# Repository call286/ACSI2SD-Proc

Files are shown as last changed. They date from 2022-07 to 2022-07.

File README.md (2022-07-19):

# ACSI2SD-Proc
version for QFP100 controller
ACSI0123_512M.xml contains default configuration for scsi2sd-util

# Hardware - finally with placement help and board layout

- Board layout isn't the original layout, it's just for helping with rough position of parts
- DRC/ERC passing
- interactive BOM in kicad folder

Board Render Front           |  Board Render Back
:-------------------------:|:-------------------------:
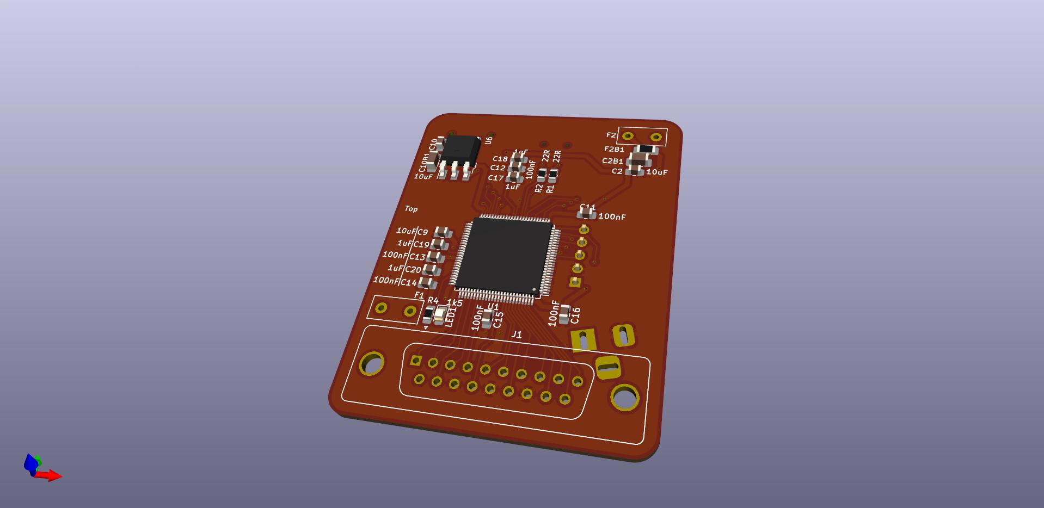
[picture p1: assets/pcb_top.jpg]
Board Render Front
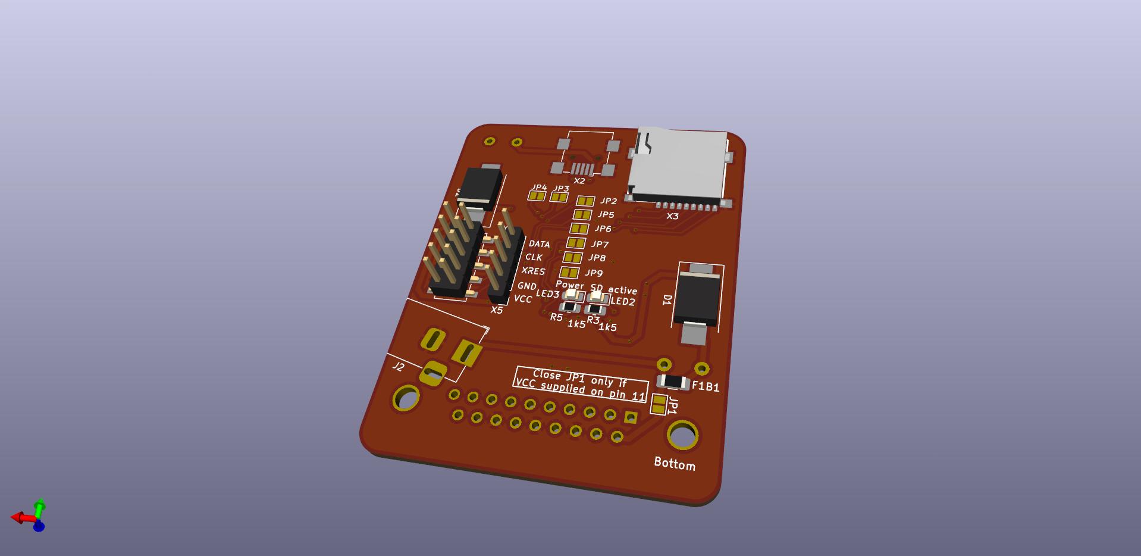
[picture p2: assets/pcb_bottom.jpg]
Board Render Back
 |

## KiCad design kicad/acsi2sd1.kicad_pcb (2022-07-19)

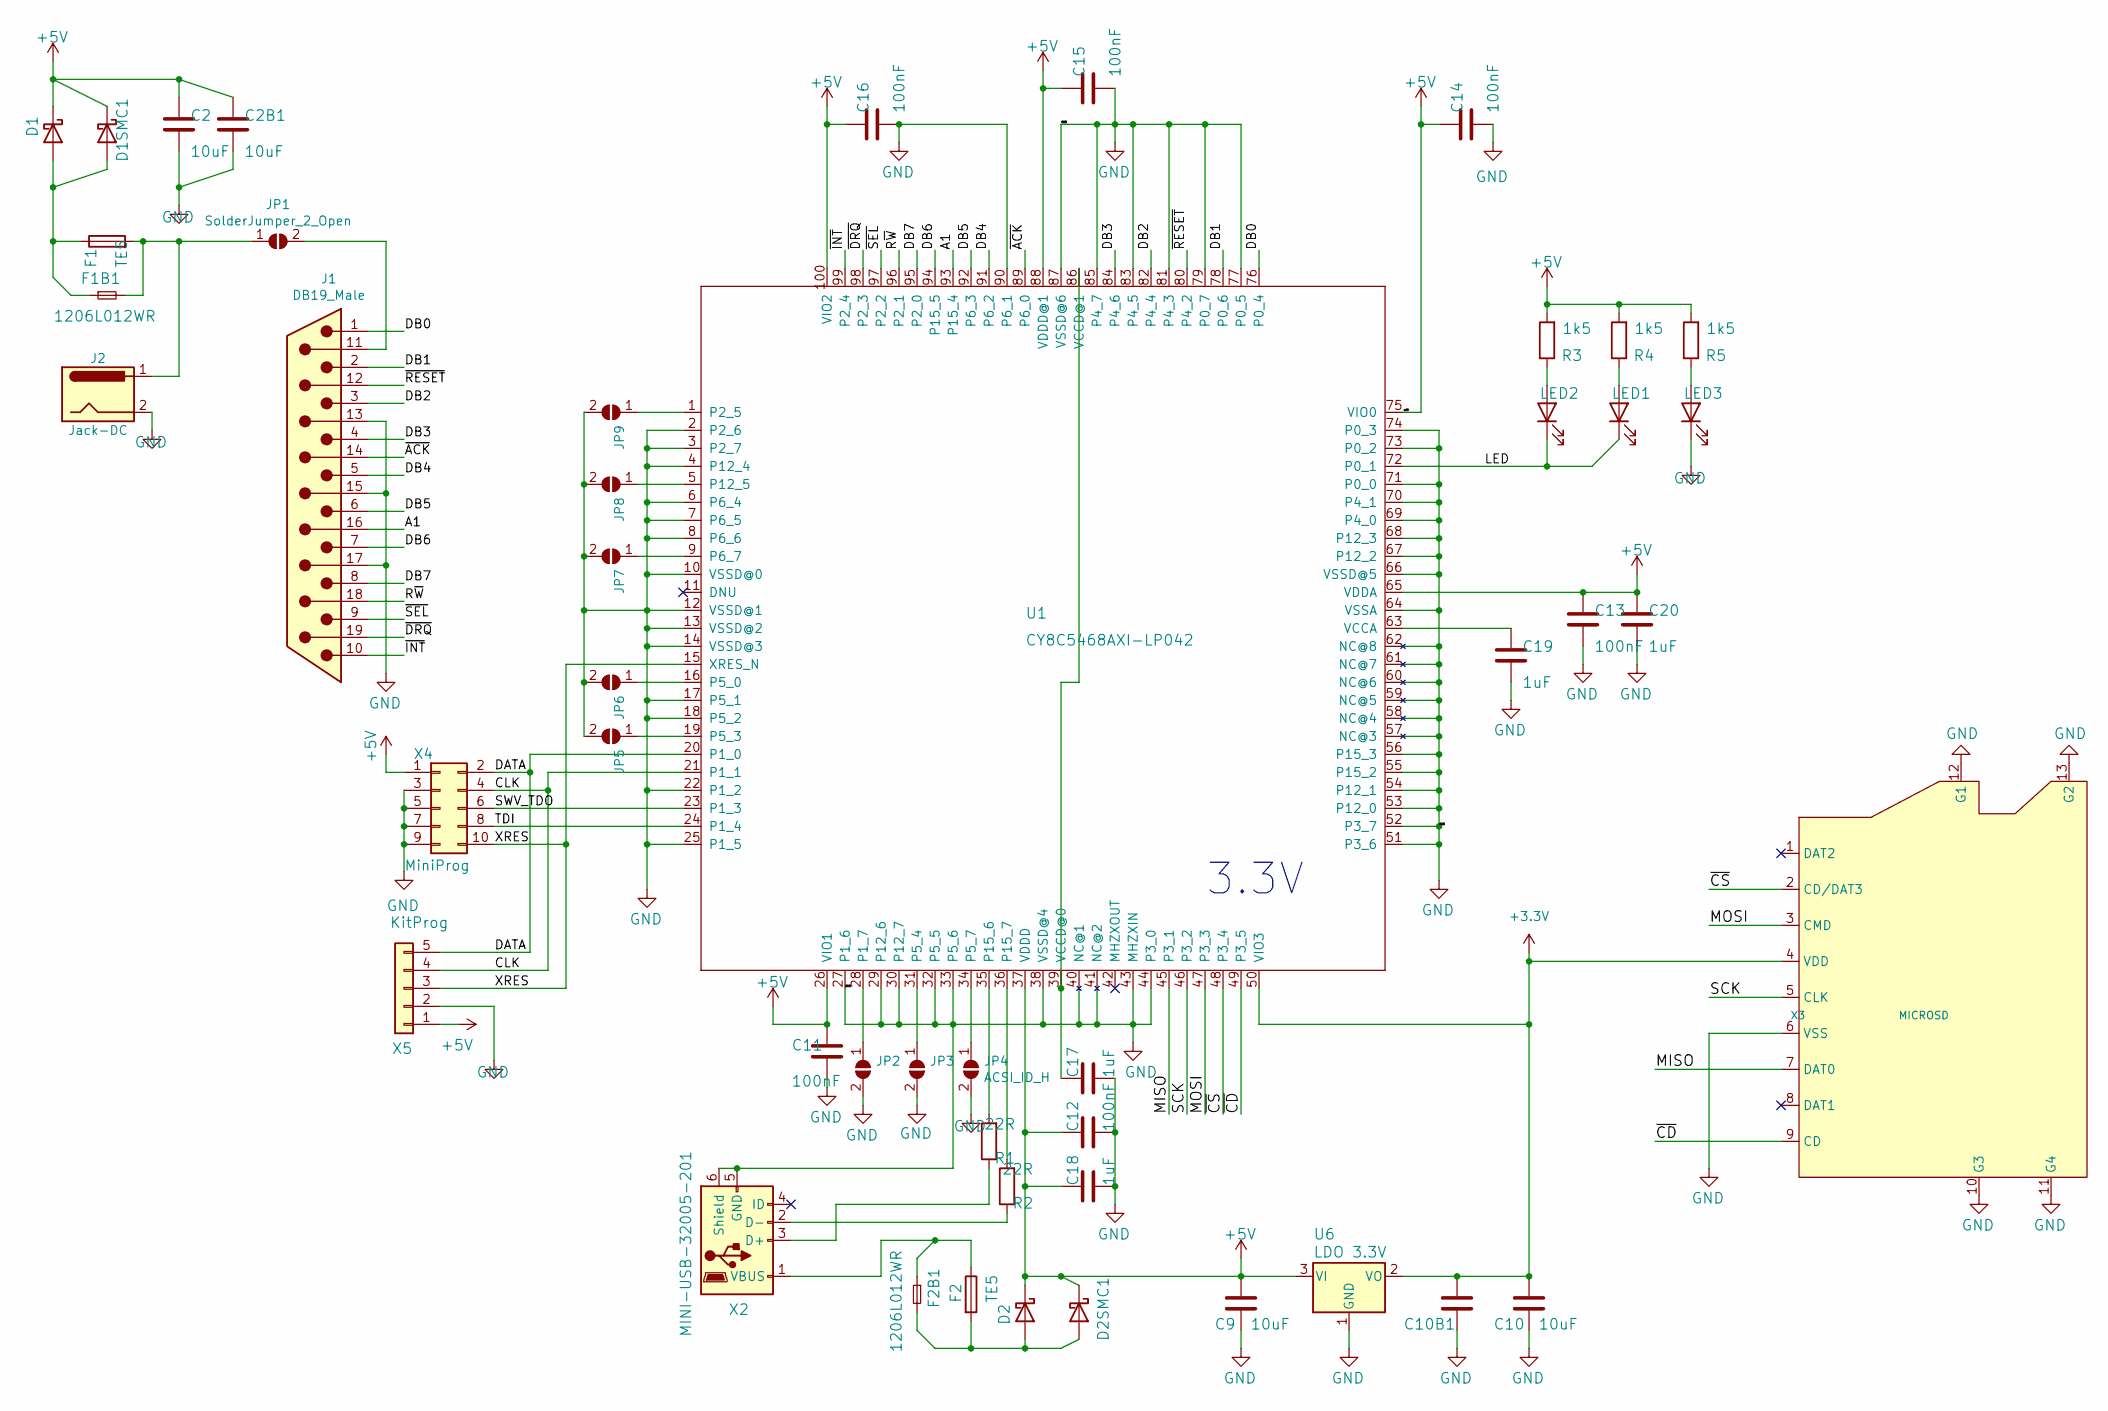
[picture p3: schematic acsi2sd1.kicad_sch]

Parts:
C2, C9, C10: 10uF; C_0805_2012Metric_Pad1.18x1.45mm_HandSolder
C2B1, C10B1: 10uF; C_1206_3216Metric_Pad1.33x1.80mm_HandSolder
C11, C12, C13, C14, C15, C16: 100nF; C_0805_2012Metric_Pad1.18x1.45mm_HandSolder
C17, C18, C19, C20: 1uF; C_0805_2012Metric_Pad1.18x1.45mm_HandSolder
D1, D2: SCHOTTKY-DIODEDO214AC; D_SMA_Handsoldering
D1SMC1, D2SMC1: SCHOTTKY-DIODESMC; D_SMC_Handsoldering
F1, F2: TE5; Fuse_Littelfuse_395Series
F1B1, F2B1: 1206L012WR; Fuse_1206_3216Metric_Pad1.42x1.75mm_HandSolder
J1: DB19_Male; DSUB-19_Male_Vertical_MountingHoles
J2: Jack-DC; BarrelJack_Horizontal
JP1, JP2, JP3, JP5, JP6, JP7, JP8, JP9: SolderJumper_2_Open; SolderJumper-2_P1.3mm_Open_Pad1.0x1.5mm
JP4: ACSI_ID_H; SolderJumper-2_P1.3mm_Open_Pad1.0x1.5mm
LED1: LEDCHIPLED_0805; LED_0805_2012Metric_Pad1.15x1.40mm_HandSolder
LED2: SD active; LED_0805_2012Metric_Pad1.15x1.40mm_HandSolder
LED3: Power; LED_0805_2012Metric_Pad1.15x1.40mm_HandSolder
R1, R2: 22R; R_0805_2012Metric_Pad1.20x1.40mm_HandSolder
R3, R4, R5: 1k5; R_0805_2012Metric_Pad1.20x1.40mm_HandSolder
U1: CY8C5468AXI-LP042; TQFP-100_14x14mm_P0.5mm
U6: LDO 3.3V; TO-252-3_TabPin2
X2: MINI-USB-32005-201; USB_Mini-B_Wuerth_65100516121_Horizontal
X3: MICROSD; lcsc_c111196_microsd_slot; LCSC Part C111196
X4: MiniProg; PinHeader_2x05_P2.54mm_Vertical_SMD
X5: KitProg; PinHeader_1x05_P2.54mm_Vertical

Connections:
+3.3V: C10.1, C10B1.1, U1.50 (VIO3), U6.2 (VO), X3.4 (VDD)
+5V: C2.1, C2B1.1, C9.1, C11.1, C12.1, C13.1, C14.1, C15.1, C16.1, C18.1, C20.1, D1.1 (K), D1SMC1.1 (K), D2.1 (K), D2SMC1.1 (K), R3.2, R4.2, R5.2, U1.26 (VIO1), U1.37 (VDDD), U1.65 (VDDA), U1.75 (VIO0), U1.88 (VDDD@1), U1.100 (VIO2), U6.3 (VI), X4.1, X5.1
/A1: J1.16, U1.93 (P15_4)
/CLK: U1.21 (P1_1), X4.4, X5.4
/DATA: U1.20 (P1_0), X4.2, X5.5
/DB0: J1.1, U1.76 (P0_4)
/DB1: J1.2, U1.78 (P0_6)
/DB2: J1.3, U1.82 (P4_4)
/DB3: J1.4, U1.84 (P4_6)
/DB4: J1.5, U1.91 (P6_2)
/DB5: J1.6, U1.92 (P6_3)
/DB6: J1.7, U1.94 (P15_5)
/DB7: J1.8, U1.95 (P2_0)
/LED: LED1.1 (K), LED2.1 (K), U1.72 (P0_1)
/MISO: U1.45 (P3_1), X3.7 (DAT0)
/MOSI: U1.47 (P3_3), X3.3 (CMD)
/R~W: J1.18, U1.96 (P2_1)
/SCK: U1.46 (P3_2), X3.5 (CLK)
/SWV_TDO: U1.23 (P1_3), X4.6
/TDI: U1.24 (P1_4), X4.8
/XRES: U1.15 (XRES_N), X4.10, X5.3
/~ACK: J1.14, U1.89 (P6_0)
/~CD: U1.49 (P3_5), X3.9 (CD)
/~CS: U1.48 (P3_4), X3.2 (CD/DAT3)
/~DRQ: J1.19, U1.98 (P2_3)
/~INT: J1.10, U1.99 (P2_4)
/~RESET: J1.12, U1.80 (P4_2)
/~SEL: J1.9, U1.97 (P2_2)
GND: C2.2, C2B1.2, C9.2, C10.2, C10B1.2, C11.2, C12.2, C13.2, C14.2, C15.2, C16.2, C17.2, C18.2, C19.2, C20.2, J1.13, J1.15, J1.17, J2.2, JP2.2 (B), JP3.2 (B), JP4.2 (B), JP5.2 (B), JP6.2 (B), JP7.2 (B), JP8.2 (B), JP9.2 (B), LED3.1 (K), U1.2 (P2_6), U1.3 (P2_7), U1.4 (P12_4), U1.6 (P6_4), U1.7 (P6_5), U1.8 (P6_6), U1.10 (VSSD@0), U1.12 (VSSD@1), U1.13 (VSSD@2), U1.14 (VSSD@3), U1.17 (P5_1), U1.18 (P5_2), U1.22 (P1_2), U1.25 (P1_5), U1.27 (P1_6), U1.29 (P12_6), U1.30 (P12_7), U1.32 (P5_5), U1.33 (P5_6), U1.38 (VSSD@4), U1.40 (NC@1), U1.41 (NC@2), U1.43 (MHZXIN), U1.44 (P3_0), U1.51 (P3_6), U1.52 (P3_7), U1.53 (P12_0), U1.54 (P12_1), U1.55 (P15_2), U1.56 (P15_3), U1.57 (NC@3), U1.58 (NC@4), U1.59 (NC@5), U1.60 (NC@6), U1.61 (NC@7), U1.62 (NC@8), U1.64 (VSSA), U1.66 (VSSD@5), U1.67 (P12_2), U1.68 (P12_3), U1.69 (P4_0), U1.70 (P4_1), U1.71 (P0_0), U1.73 (P0_2), U1.74 (P0_3), U1.77 (P0_5), U1.79 (P0_7), U1.81 (P4_3), U1.83 (P4_5), U1.85 (P4_7), U1.87 (VSSD@6), U1.90 (P6_1), U6.1 (GND), X2.5 (GND), X2.6 (Shield), X3.6 (VSS), X3.10 (G3), X3.11 (G4), X3.12 (G1), X3.13 (G2), X4.3, X4.5, X4.7, X4.9, X5.2
unnamed: C17.1, U1.39 (VCCD@0), U1.86 (VCCD@1)
unnamed: C19.1, U1.63 (VCCA)
unnamed: D1.2 (A), D1SMC1.2 (A), F1.1, F1B1.1
unnamed: D2.2 (A), D2SMC1.2 (A), F2.2, F2B1.2
unnamed: F1.2, F1B1.2, J2.1, JP1.1 (A)
unnamed: F2.1, F2B1.1, X2.1 (VBUS)
unnamed: J1.11, JP1.2 (B)
unnamed: JP2.1 (A), U1.28 (P1_7)
unnamed: JP3.1 (A), U1.31 (P5_4)
unnamed: JP4.1 (A), U1.34 (P5_7)
unnamed: JP5.1 (A), U1.19 (P5_3)
unnamed: JP6.1 (A), U1.16 (P5_0)
unnamed: JP7.1 (A), U1.9 (P6_7)
unnamed: JP8.1 (A), U1.5 (P12_5)
unnamed: JP9.1 (A), U1.1 (P2_5)
unnamed: LED1.2 (A), R4.1
unnamed: LED2.2 (A), R3.1
unnamed: LED3.2 (A), R5.1
unnamed: R1.1, X2.3 (D+)
unnamed: R1.2, U1.35 (P15_6)
unnamed: R2.1, X2.2 (D-)
unnamed: R2.2, U1.36 (P15_7)

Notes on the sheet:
3.3V

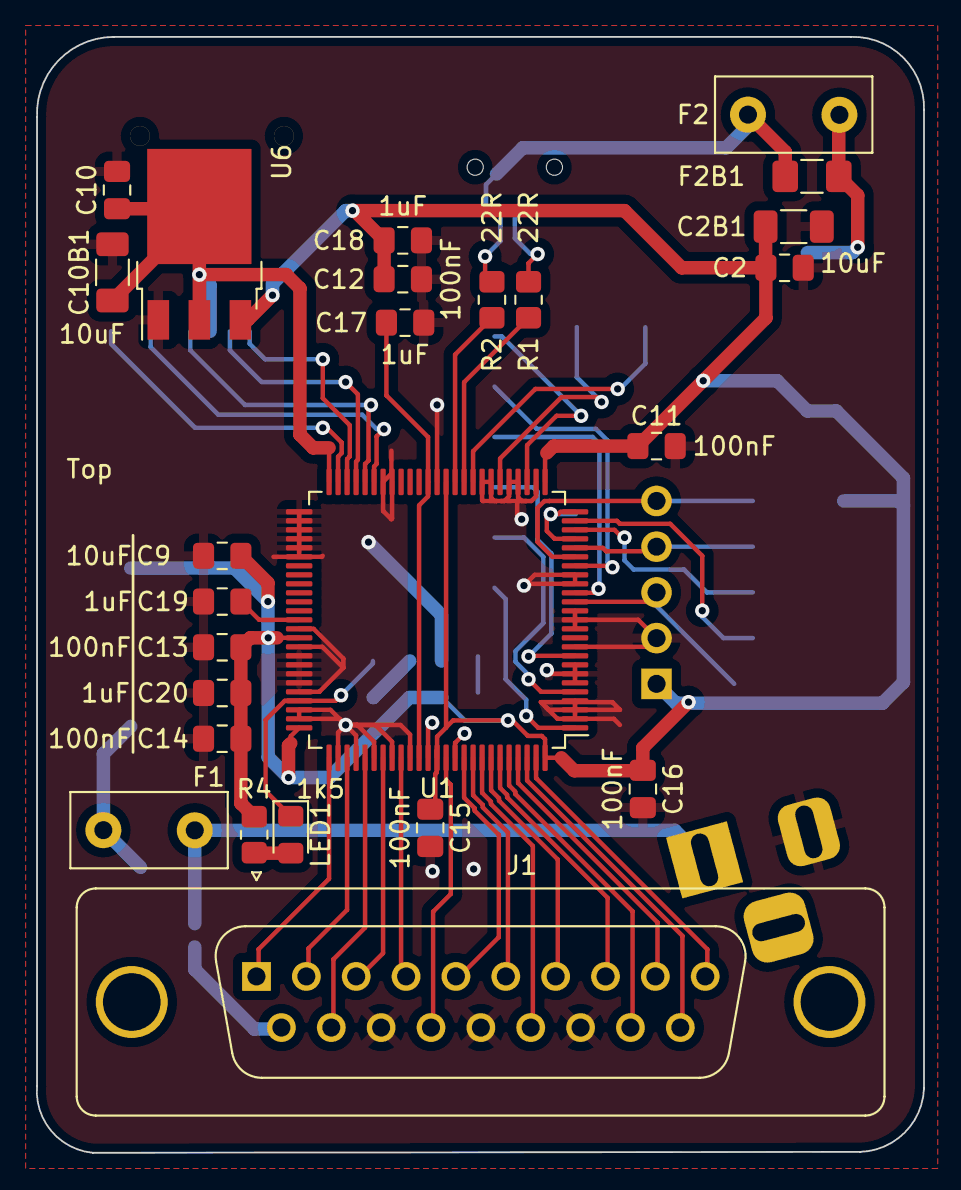
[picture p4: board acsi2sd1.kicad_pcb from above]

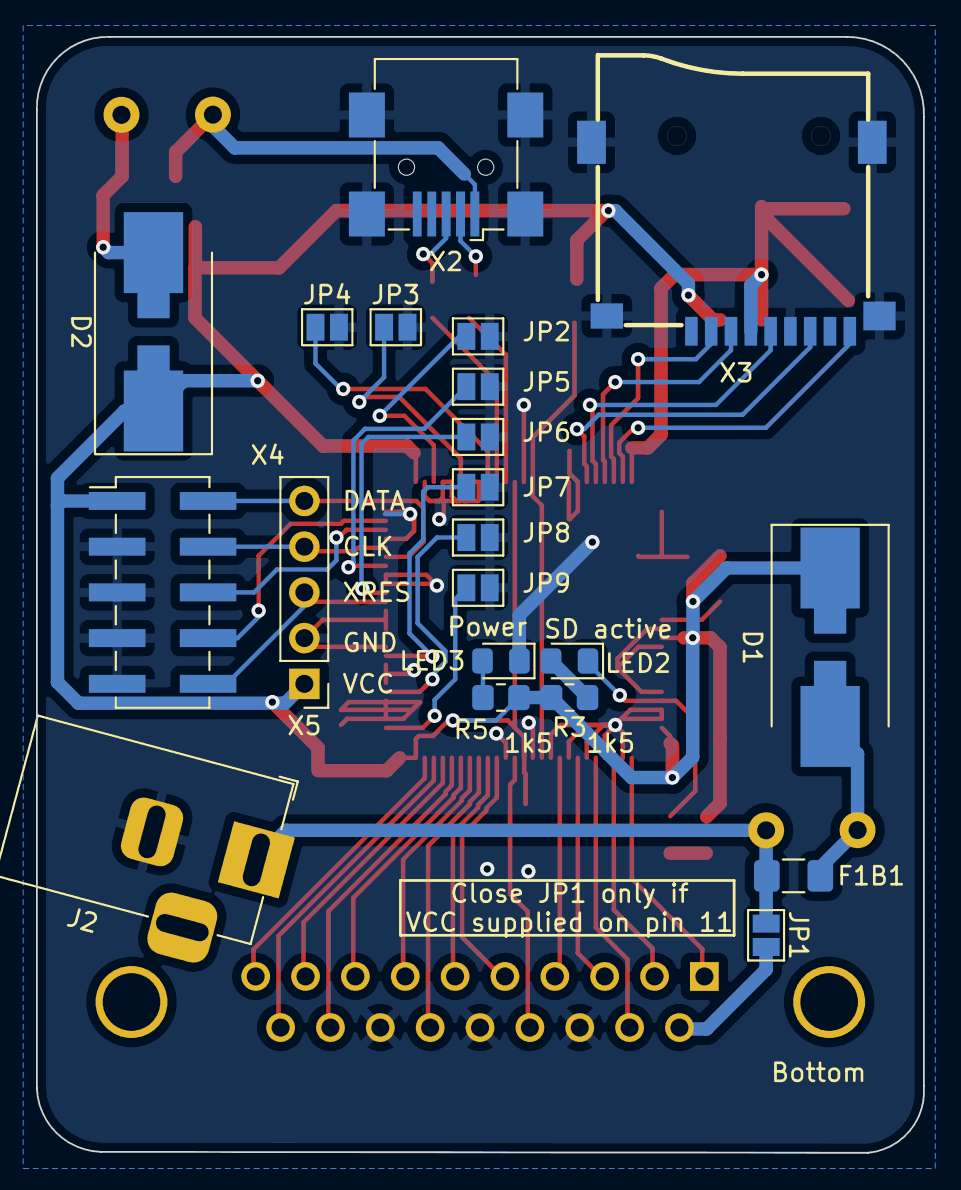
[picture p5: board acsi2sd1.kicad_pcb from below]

Board: 2 copper layers, 49.3 x 62.0 mm, 48 parts (23 on the bottom side), 51 nets.
